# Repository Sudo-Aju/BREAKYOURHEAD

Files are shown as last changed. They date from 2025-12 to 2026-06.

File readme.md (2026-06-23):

<div align="center">

# BYH MacroPad

### A custom 6-key macropad built for professional video editing workflows.



<br>






</div>

---

# Overview

BYH is a compact **6-key mechanical macropad** designed specifically for video editors using applications like **Adobe Premiere Pro** and **DaVinci Resolve**.

Rather than relying on keyboard shortcuts, BYH places the most frequently used editing functions beneath your fingertips while providing two precision rotary encoders for intuitive timeline control.

The device runs **QMK Firmware**, allowing every key, encoder, and layer to be fully customizable.

---

# Features

- 6-key mechanical layout
- Dual EC11 rotary encoders
- 0.91" OLED display
- QMK Firmware
- Layer switching
- Custom PCB
- Silent linear mechanical switches
- Heavy aluminum encoder knobs
- Ergonomic 5–7° angled case
- USB-C connectivity

---

# Hardware

| Component | Specification |
|---|---|
| **Microcontroller** | Seeed Studio XIAO RP2040 |
| **Keys** | 6 × Cherry MX Mechanical Switches |
| **Encoders** | 2 × EC11 Rotary Encoders |
| **Display** | 0.91" OLED (I²C) |
| **Firmware** | QMK |
| **PCB** | Custom FR4 PCB |
| **Case** | 3D Printed |
| **Connection** | USB-C |

---

# Layers

## Layer 0 — Rough Cut

Primary editing controls.

| Control | Function |
|---|---|
| Keys | Cut, Ripple Delete, Undo, Redo, Play/Pause, Marker |
| Left Encoder | Timeline Scrub |
| Right Encoder | Timeline Zoom |

---

## Layer 1 — Color & Audio

Color grading and audio adjustments.

| Control | Function |
|---|---|
| Keys | Color Wheels, Curves, Gain, Saturation, Audio Tools |
| Left Encoder | Parameter Adjustment |
| Right Encoder | Fine Control |

---

# Bill of Materials

| Part | Qty | Specification |
|---|----:|---|
| Seeed Studio XIAO RP2040 | 1 | Microcontroller |
| 0.91" OLED Display | 1 | I²C |
| EC11 Rotary Encoder | 2 | Push-button |
| Cherry MX Switch | 6 | Linear |
| DSA 1u Keycaps | 6 | Low Profile |
| Custom PCB | 1 | FR4 |
| 1N4148 Diodes | 6 | Through-hole |
| M3 Heat-set Inserts | 5 | Brass |
| M3×12 SHCS Screws | 2 | Steel |
| M3×16 SHCS Screws | 3 | Steel |

---

# Gallery

<p align="center">

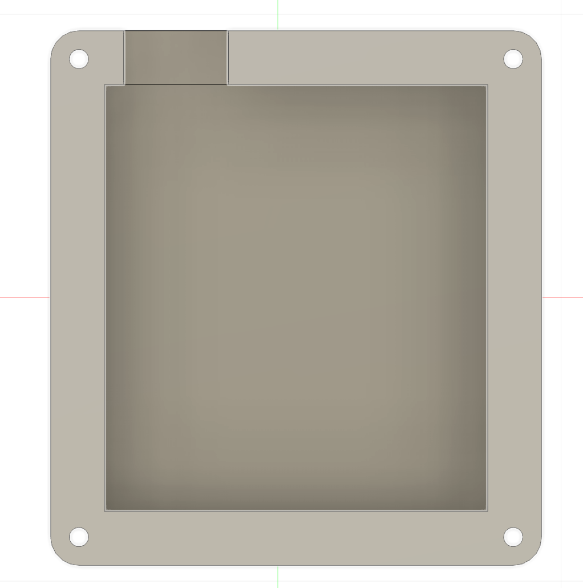
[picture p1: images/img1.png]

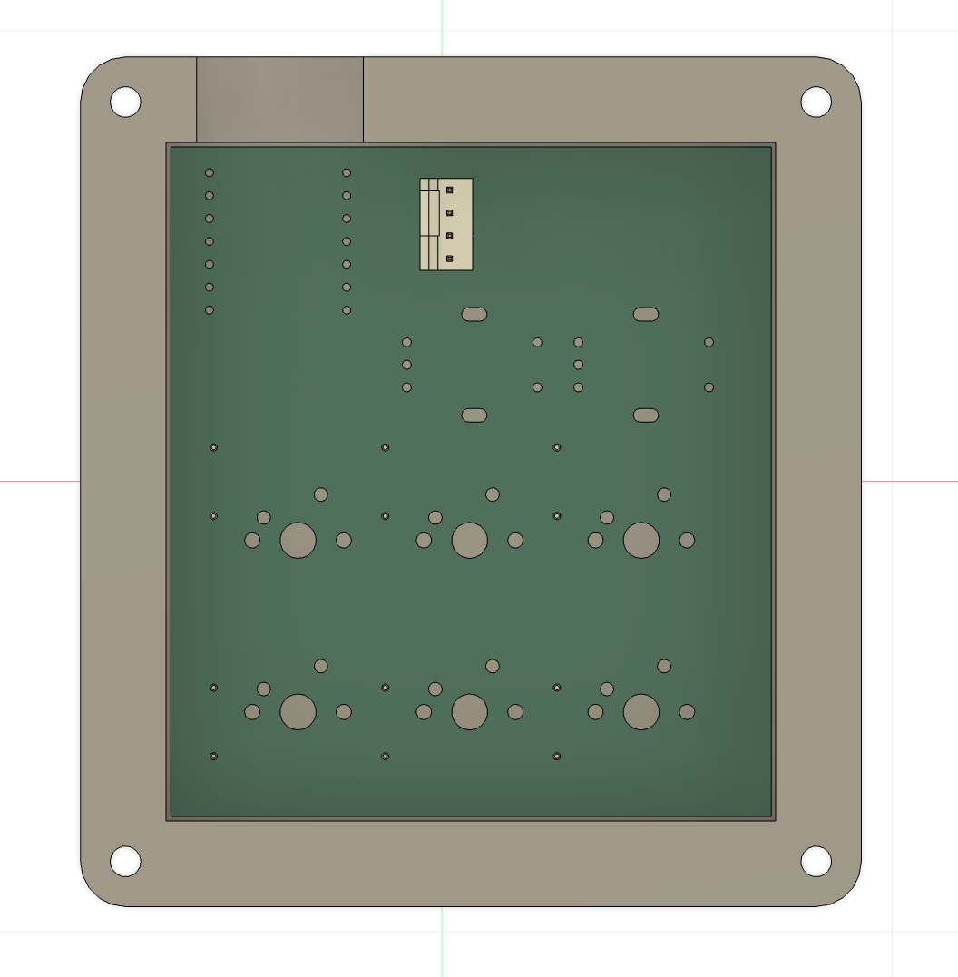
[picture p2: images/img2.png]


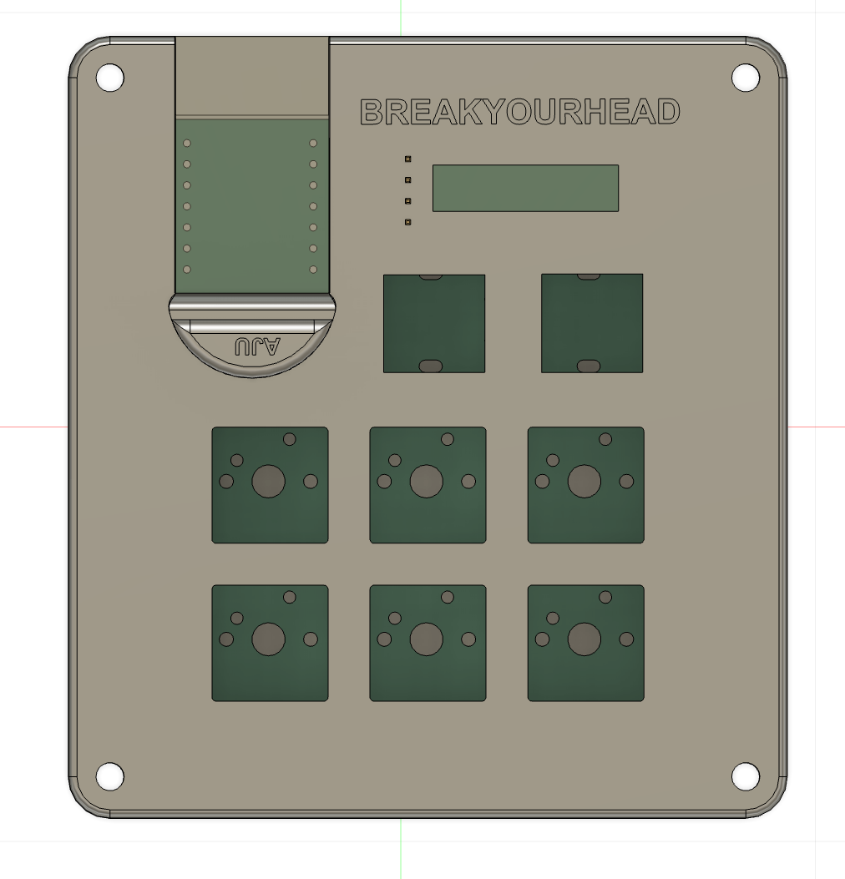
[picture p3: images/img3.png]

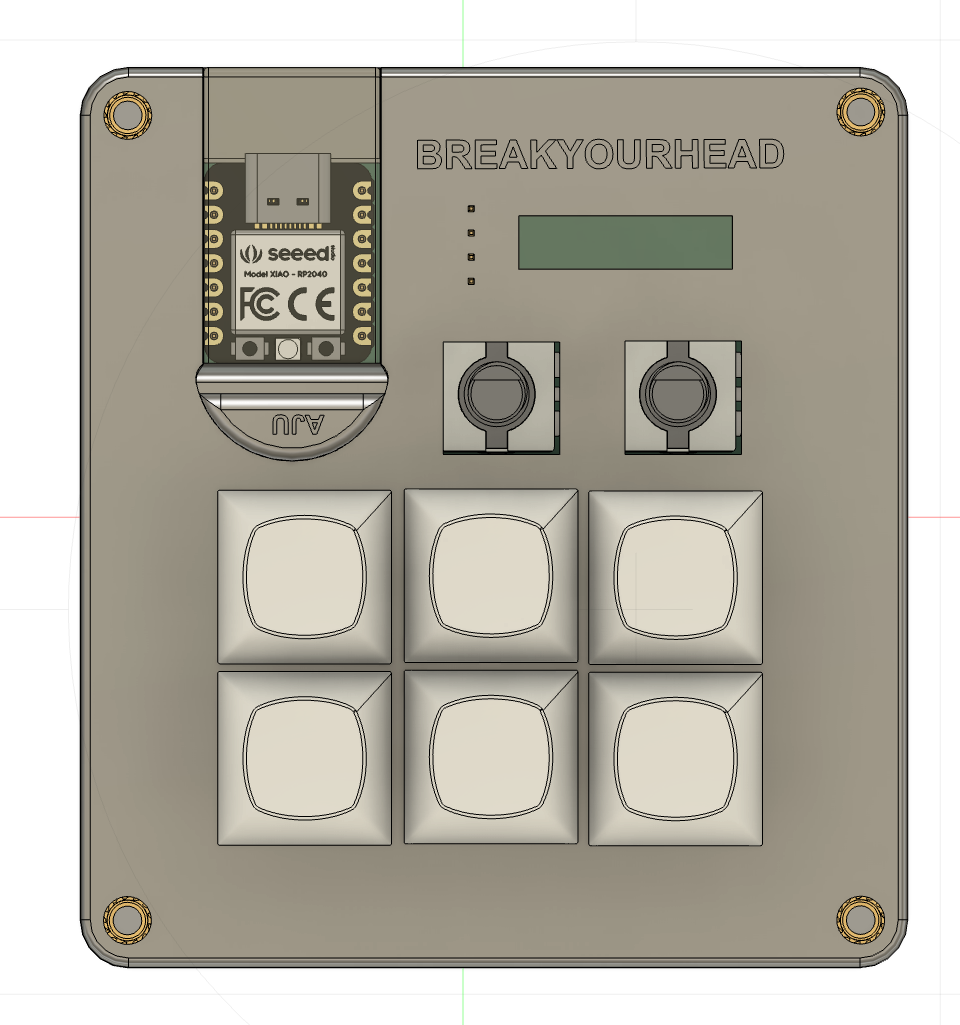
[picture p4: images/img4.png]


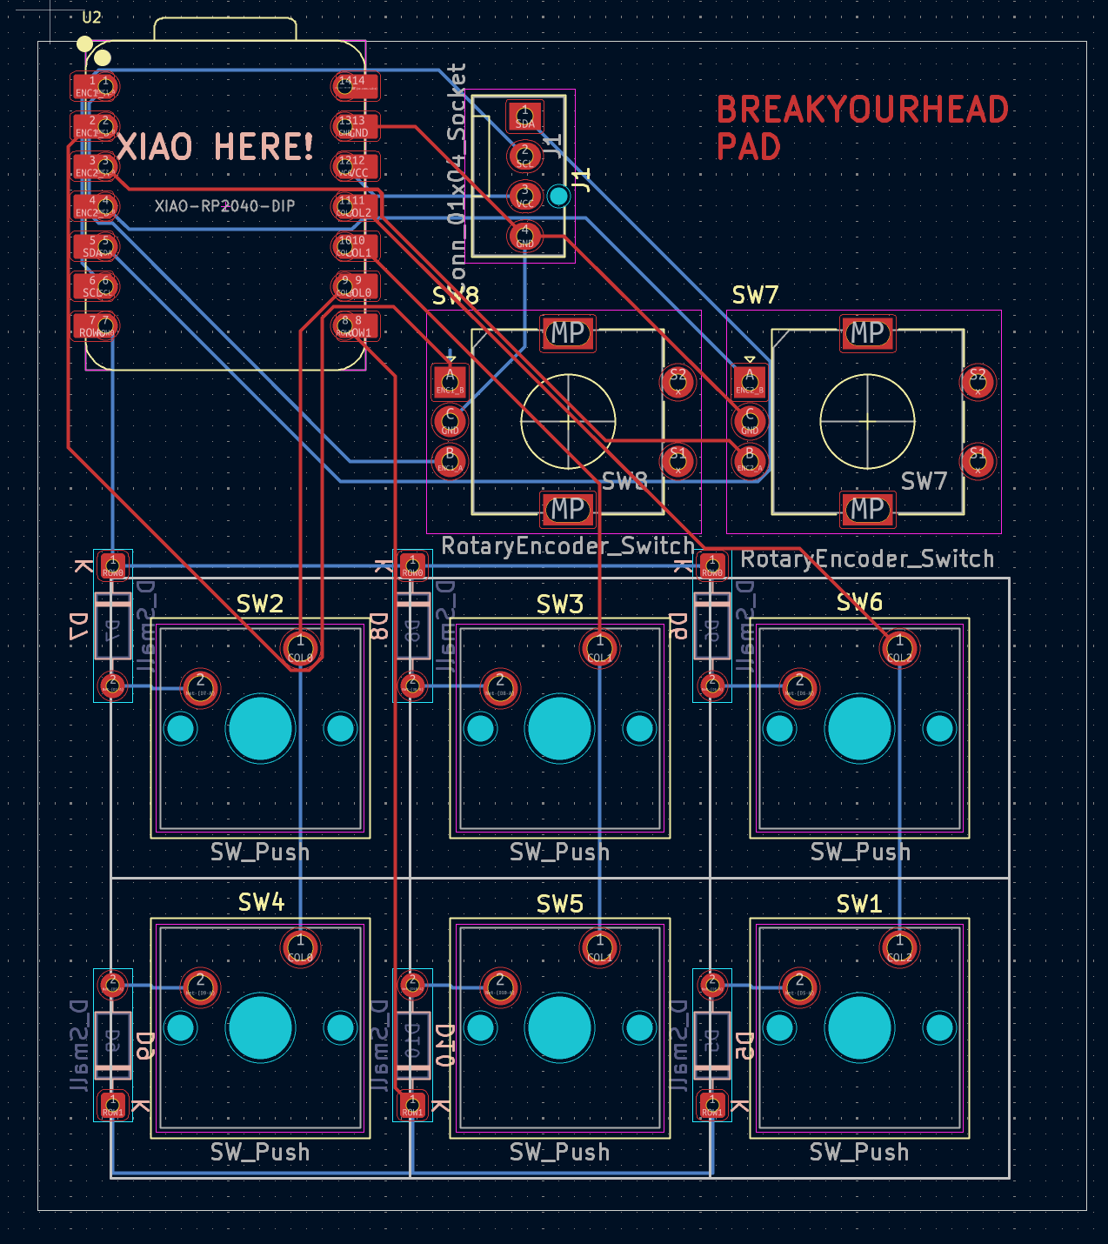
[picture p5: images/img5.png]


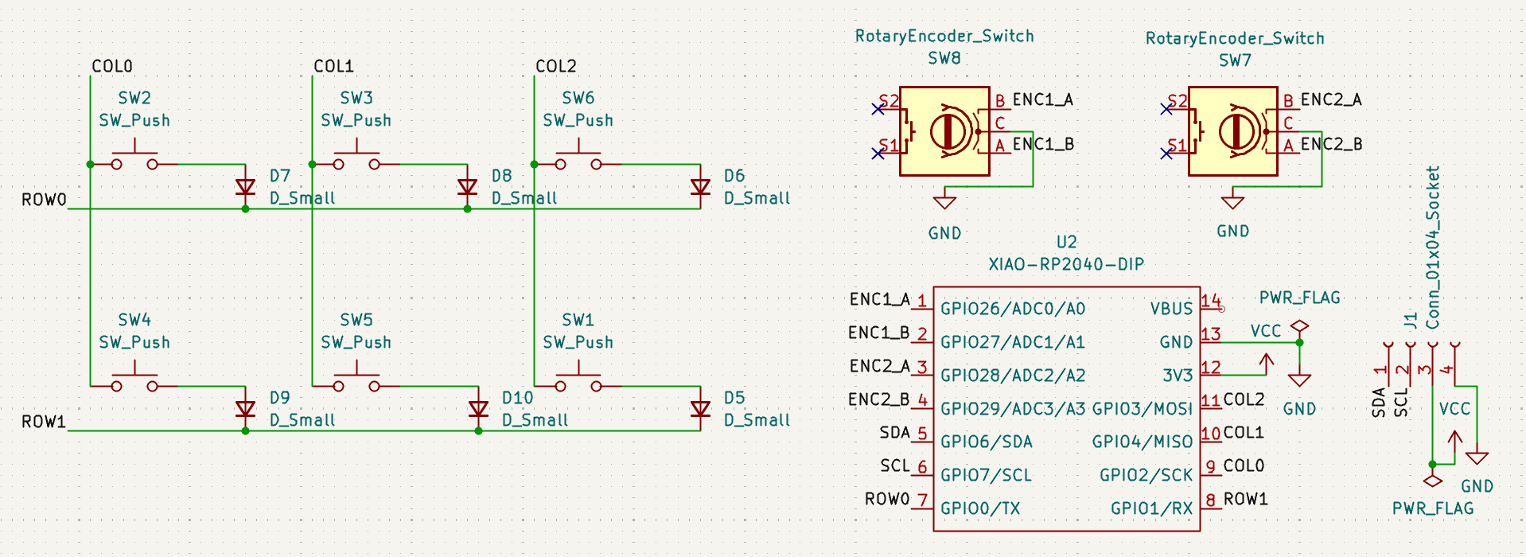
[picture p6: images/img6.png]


</p>

---

# Why BYH?

Traditional keyboards force editors to remember dozens of shortcuts.

BYH transforms the most frequently used editing commands into dedicated tactile controls, reducing hand movement while improving speed and workflow efficiency.

---

# Future Improvements

- RGB lighting
- Wireless mode
- VIA compatibility
- Multiple OLED pages
- Application auto-detection
- Additional editing profiles

---

<div align="center">

### Designed for creators who spend more time editing than searching for shortcuts.

</div>

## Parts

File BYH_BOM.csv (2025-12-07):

Part Name | Quantity | Specifications | Notes
Microcontroller | 1 | Seeed Studio XIAO RP2040 | Main logic board
Display | 1 | 0.91in OLED Module | I2C Interface
Rotary Encoders | 2 | EC11 v2 | With push-button
Switches | 6 | Cherry MX Switch Base v2 | Mechanical Keys
Keycaps | 6 | DSA 1u v2 | Low profile profile
Inserts | 8 | M3 Threaded Insert v3 | Heat-set for Case
Screws (Short) | 4 | M3x12 SHCS v1 | Socket Head Cap Screw
Screws (Long) | 4 | M3x16 SHCS v5 | Socket Head Cap Screw
PCB | 1 | Custom BYH PCB | FR4
Diodes | 6 | 1N4148 | Through-hole

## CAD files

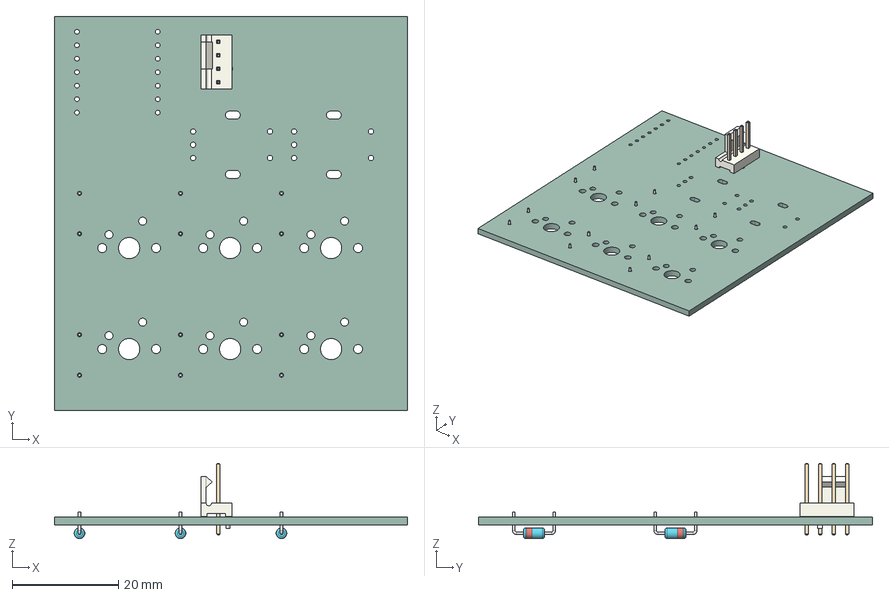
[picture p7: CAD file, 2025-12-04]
BYH_PCB/MacroPad.step
66.7 x 74.3 x 14.2 mm
FanPinHeader_1x04_P2.54mm_Vertical
D_DO-35_SOD27_P7.62mm_Horizontal x 6
MacroPad_PCB

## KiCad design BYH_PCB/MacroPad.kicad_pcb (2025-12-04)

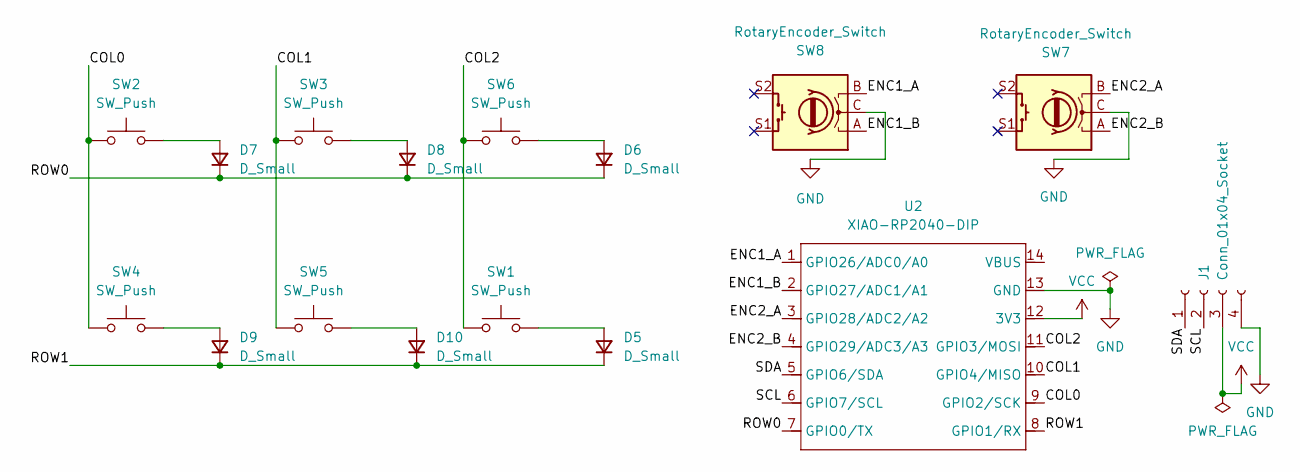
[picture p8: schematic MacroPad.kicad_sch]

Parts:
D5, D6, D7, D8, D9, D10: D_Small; D_DO-35_SOD27_P7.62mm_Horizontal
J1: Conn_01x04_Socket; FanPinHeader_1x04_P2.54mm_Vertical
SW1, SW2, SW3, SW4, SW5, SW6: SW_Push; SW_Cherry_MX_1.00u_PCB
SW7, SW8: RotaryEncoder_Switch; RotaryEncoder_Alps_EC11E-Switch_Vertical_H20mm
U2: XIAO-RP2040-DIP

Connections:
/COL0: SW2.1, SW4.1, U2.9 (GPIO2/SCK)
/COL1: SW3.1, SW5.1, U2.10 (GPIO4/MISO)
/COL2: SW1.1, SW6.1, U2.11 (GPIO3/MOSI)
/ENC1_A: SW8.B, U2.1 (GPIO26/ADC0/A0)
/ENC1_B: SW8.A, U2.2 (GPIO27/ADC1/A1)
/ENC2_A: SW7.B, U2.3 (GPIO28/ADC2/A2)
/ENC2_B: SW7.A, U2.4 (GPIO29/ADC3/A3)
/ROW0: D6.1 (K), D7.1 (K), D8.1 (K), U2.7 (GPIO0/TX)
/ROW1: D5.1 (K), D9.1 (K), D10.1 (K), U2.8 (GPIO1/RX)
/SCL: J1.2, U2.6 (GPIO7/SCL)
/SDA: J1.1, U2.5 (GPIO6/SDA)
GND: J1.4, SW7.C, SW8.C, U2.13 (GND)
unnamed: D5.2 (A), SW1.2
unnamed: D6.2 (A), SW6.2
unnamed: D7.2 (A), SW2.2
unnamed: D8.2 (A), SW3.2
unnamed: D9.2 (A), SW4.2
unnamed: D10.2 (A), SW5.2
VCC: J1.3, U2.12 (3V3)

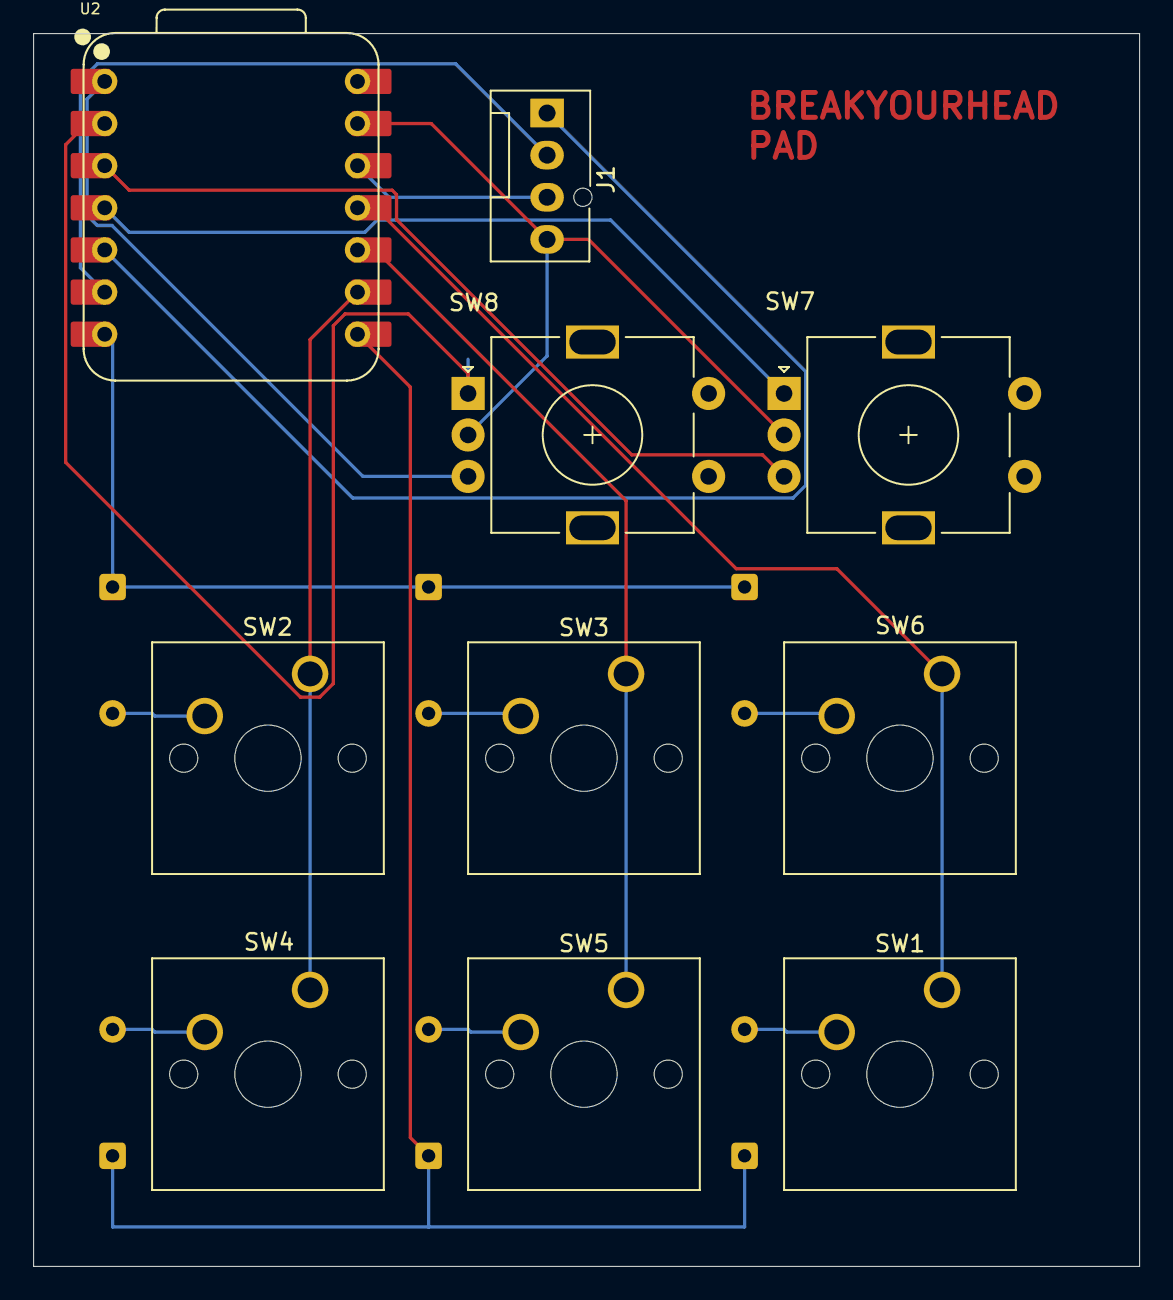
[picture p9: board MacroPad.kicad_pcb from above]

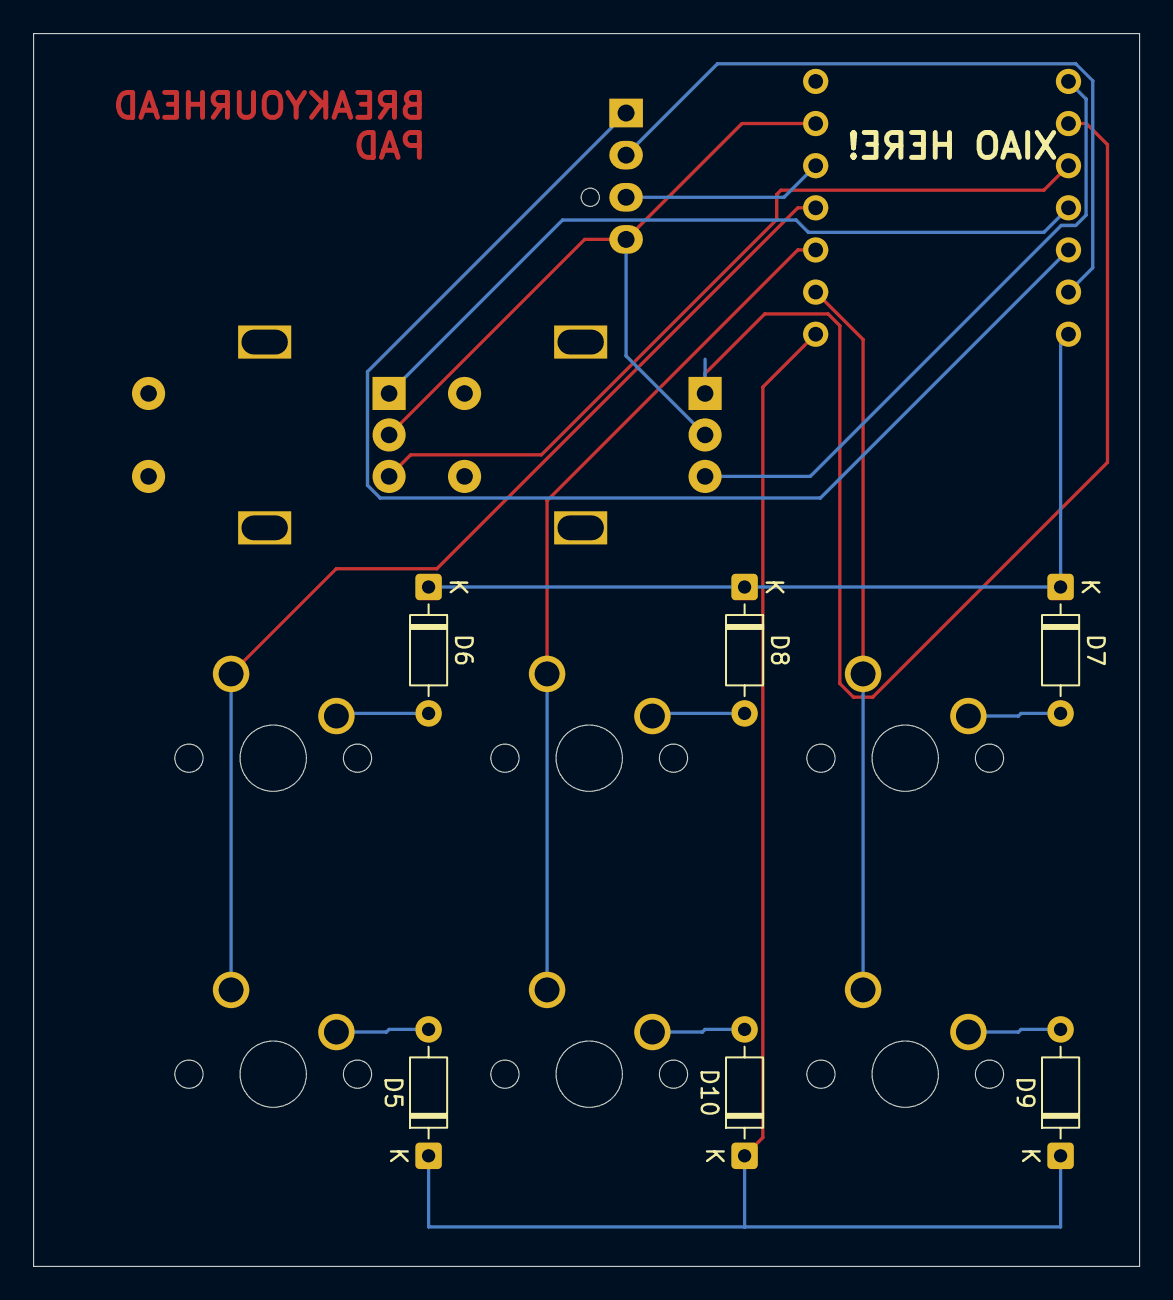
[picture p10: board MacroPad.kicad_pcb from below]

Board: 2 copper layers, 66.7 x 74.3 mm, 16 parts (6 on the bottom side), 19 nets.

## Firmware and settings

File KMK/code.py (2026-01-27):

import board
import busio
import time
import displayio
import terminalio
import random
import adafruit_displayio_ssd1306
from adafruit_display_text import label

from kmk.kmk_keyboard import KMKKeyboard
from kmk.keys import KC
from kmk.scanners import DiodeOrientation
from kmk.modules.encoder import EncoderHandler
from kmk.extensions import Extension
from kmk.extensions.media_keys import MediaKeys

class StopwatchScreen(Extension):
    def __init__(self):

        self.start_time = time.monotonic()

        self.screen_ok = False
        self.stars = []
        try:
            displayio.release_displays()
            self.i2c = busio.I2C(board.D5, board.D4)
            self.display_bus = displayio.I2CDisplay(self.i2c, device_address=0x3C)
            self.display = adafruit_displayio_ssd1306.SSD1306(
                self.display_bus, width=128, height=64)
            
            self.group = displayio.Group()
            
            for i in range(15):
                star = label.Label(terminalio.FONT, text=".", color=0xFFFFFF)
                star.x = random.randint(0, 128)
                star.y = random.randint(0, 64)
                self.stars.append(star)
                self.group.append(star)


            self.header = label.Label(terminalio.FONT, text="SESSION TIME", color=0xFFFFFF, x=30, y=10)
            self.timer_label = label.Label(terminalio.FONT, text="00:00", color=0xFFFFFF, x=25, y=35, scale=3)
            
            self.group.append(self.header)
            self.group.append(self.timer_label)
            self.display.root_group = self.group
            self.screen_ok = True
        except:
            self.screen_ok = False

    def on_runtime_enable(self, keyboard): return
    def on_runtime_disable(self, keyboard): return
    def during_bootup(self, keyboard): return
    def before_matrix_scan(self, keyboard): return
    
    def after_matrix_scan(self, keyboard):
        if not self.screen_ok: return
        
        if random.random() > 0.8:
            star = random.choice(self.stars)
            star.x = (star.x - 1) % 128
            star.y = (star.y + random.randint(-1, 1)) % 64

        elapsed = time.monotonic() - self.start_time
        

        minutes = int(elapsed // 60)
        seconds = int(elapsed % 60)
        time_str = "{:02d}:{:02d}".format(minutes, seconds)
        
        try:
            self.timer_label.text = time_str
        except: pass
        return


keyboard = KMKKeyboard()
keyboard.extensions.append(MediaKeys())
keyboard.extensions.append(StopwatchScreen())

keyboard.row_pins = (board.D6, board.D7)
keyboard.col_pins = (board.D8, board.D9, board.D10)
keyboard.diode_orientation = DiodeOrientation.COL2ROW

encoder_handler = EncoderHandler()
encoder_handler.pins = ((board.D0, board.D1, None, False), (board.D2, board.D3, None, False))
keyboard.modules.append(encoder_handler)



keyboard.keymap = [[KC.LGUI(KC.C), KC.LGUI(KC.V), KC.LGUI(KC.LBRC), KC.LGUI(KC.Z), KC.LGUI(KC.LSFT(KC.Z)), KC.LGUI(KC.RBRC)]]

encoder_handler.map = [[(KC.PGUP, KC.PGDN), (KC.LGUI(KC.MINUS), KC.LGUI(KC.EQUAL))]]

if __name__ == '__main__':
    keyboard.go()

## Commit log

2025-12-04 Enhance README with project details and instructions
    Expanded README to include detailed project description, BOM, features, build guide, and firmware instructions.
2025-12-04 Update README by removing firmware badge and sections
    Removed firmware badge and additional requirements sections. Updated descriptions for diodes and display components.
2025-12-04 Remove main content from README file
    Removed the main content and structure of the README file, including the header, BOM, and gallery sections.
